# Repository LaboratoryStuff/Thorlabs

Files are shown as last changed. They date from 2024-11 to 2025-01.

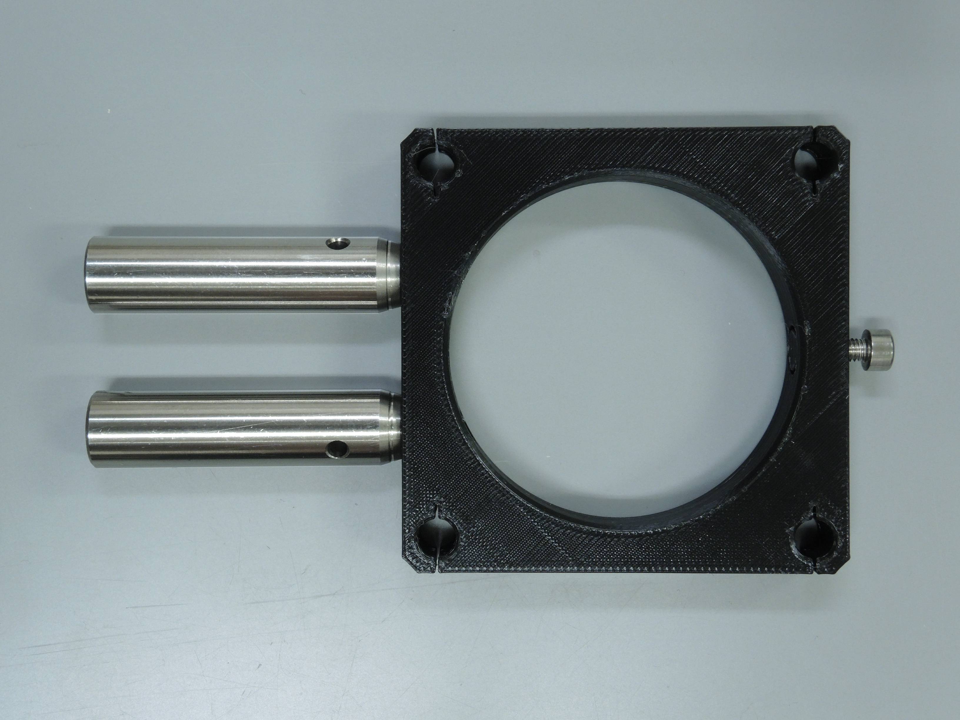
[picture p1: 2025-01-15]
THR-120-010 Cage 60 SM2/Photos/THR-120-010_Photo_05.JPG

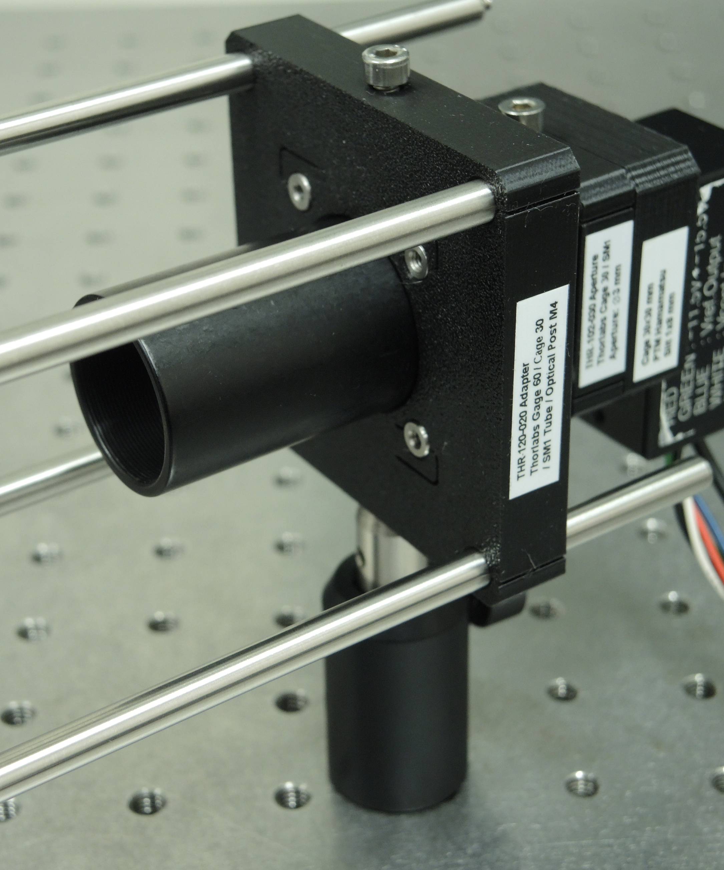
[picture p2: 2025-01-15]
THR-120-020 Cage 60 to 30/Photos/THR-120-020_Photo12.JPG

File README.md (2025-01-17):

# Thorlabs
---

This repository has the following content:
- Motor Stage Class : A Matlab class was developed based on existing code by Andriy Chmyrov (from Helmholtz Zentrum Muenchen), and posteriorly extended by Julan A.J. Fells (from Dept. Engineering Science, University of Oxford). The new class builds on top of the previous class by adding a new Thorlabs series of controllers (Thorlabs BSC201, BSC202 and BSC203), expands the use of the other controllers to work with both rotation and linear stages, adds new functions and makes the class compatible with both 32 and 64-bit Matlab libraries.
- THR-100-010 : Slit 1 mm compatible with Thorlabs Cage 30 mm system and Thorlabs SM1 external tube.
- THR-100-015 : Slit 1.5 mm. Check THR-100-010 for more details.
- THR-100-020 : Slit 2 mm. Check THR-100-010 for more details.
- THR-100-030 : Slit 3 mm. Check THR-100-010 for more details.
- THR-100-050 : Slit 5 mm. Check THR-100-010 for more details.
- THR-101-010 : Adapter, with fixed aperture 5 mm diameter, between Thorlabs Cage 30 mm, Thorlabs SM1 external tube, Thorlabs S05 external tube, optical posts with set screws M4 and Hamamatsu detectors with M2 screw (4 mm deep) grit by 14 x 14 mm. The adapter fits with a width range of photomultipliers (PTM) from Hamamatsu such as the series H9656, H10722, H10723, H11902, H11903, H14603, H16146, H14600/H14601, H14950, H14951, H14990,
H16200, H16201, H16204, H10720, H10721, H11526, H11706, H11900, H11901, H12056, H14600, H14601, H12386, H10682, H11890, H11890, ...
- THR-101-110 : Adapter between Thorlabs Cage 30 mm, Thorlabs SM1 external tube and Hamamatsu detectors with heatsink of the A3179 series.
- THR-102-030 : Fixed aperture 3 mm diameter. Check THR-102-050 for more details.
- THR-102-040 : Fixed aperture 4 mm diameter. Check THR-102-050 for more details.
- THR-102-050 : Fixed aperture 5 mm diameter compatible with Thorlabs Cage 30 mm system, Thorlabs SM1 external tube and optical posts with M4 thread.
- THR-102-060 : Fixed aperture 6 mm diameter. Check THR-102-050 for more details.
- THR-102-070 : Fixed aperture 7 mm diameter. Check THR-102-050 for more details.
- THR-120-010 : Adapter between Thorlabs Cage 60 mm, Thorlabs SM2 external tube and optical post with set screw M4.
- THR-120-020 : Adapter between Thorlabs Cage 60 mm, Thorlabs Cage 30 mm, Thorlabs SM1 external tube and optical post with set screw M4.
- Thorlabs Camera Class: A Matlab class was developed to get images from Thorlabs cameras compatible with uc480DotNet.dll. This class was tested with a single Thorlabs DCC1545M camera and with ThorCam 64-bits. Nonetheless, this class is designed to operate with other Thorlabs cameras of the same family.
- Thorlabs IP250-BV P/N-type laser diodes : Modification of the IP250-BV laser diode drive board to operate with n-type and p-type laser diodes.

---

Content in other repositories compatible with Thorlabs parts:
- JAI repository, JAI-001-010 : Base adapter between JAI camera BM-141GE / BB-141GE with optical posts with M4 or M6 threads.
- JAI repository, JAI-001-020 : Front plate adapeter between JAI camera BM-141GE / BB-141GE with optical posts with M4 thread, Thorlabs Cage 30 mm and Thorlabs SM1 tube.

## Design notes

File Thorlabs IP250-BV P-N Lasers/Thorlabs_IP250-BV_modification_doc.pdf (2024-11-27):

# Thorlabs IP250BV Modifications

Date: 2024-11-27
Author: F.O.

## 1. Summary

The present document describes a modificaon of a Thorlabs IP250-BV laser diode driver board to work with laser diodes of both n and p-type, i.e., with laser diodes with grounded anodes or grounded cathodes. This is accomplished by adding the missing components in posions JMP1, D6 and K2.

## 2. Introducon

Thorlabs offers several laser diode driver boards. Two of these drivers are the Thorlabs IP500 and Thorlabs IP250BV. The last driver is opmised for laser diodes operang with high voltages such as blue-violet lasers (check Thorlabs IP250-BV manual for more details). The main differences of the IP250BV relave to the IP500 are:
- Capable to operate diodes with higher voltages (8 Vdc instead of 3 Vdc);
- Maximum current of 250 mA (instead of 500 mA);
- Can only operate n-type laser diodes (Style B, C and H).

## 3. Board Details

When both boards are compared the head connector JMP1, diode D6 and relay K2 components are missing in the IP250BV board. In the IP500 board, the JMP1 connector selects the laser diode with grounded anodes or cathodes. The K2 relay changes the polarity of the diode connecon. The D6 diode is in parallel with the relay coil (with opposite polarity) to prevent damage to other components when turned off.
Instead of the K2 relay, the IP250-BV board has 2 jumper wires between pins 3-4 and 9-10 (see Figure 1). This corresponds to the de-energized connecons of the relay.

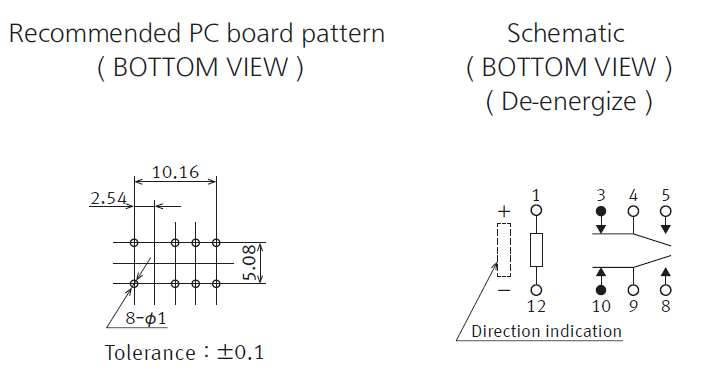
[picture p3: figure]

Figure 1: Schemes of the TX2-12V pins.

The PCB is the same for both laser drivers (boom side: 3037-002, Rev. D, IP1000-PC1). The comparison between an IP250- BV (Front side label: I250-Assy1, Rev. A) and an IP500 (Front side label: I500-Assy1, Rev. D) reveals that only some components are different. In the IP250-BV, the components U1, U2, U3 and U6 are quad FET-input operaonal amplifiers Burr Brown OPA 4137U. In the case of the IP500, U1, U2 and U3 are quad operaonal amplifiers TLC274C and the U6 is a quad operaonal amplifier LMC6484. These components do not change the operaonal funcon of the board. In the IP250-BV the relay is a TX2-12V (12 volts operaon) and in the IP500 the relays are TX2-5V (5 volts operaon).
Secon 5 provides photos of the IP250-BV board and secon 6 provides a list of some of the components of the IP250-BV board.

## 4. Board Modificaon

The IP250-BV can be modified to work with both laser diodes with grounded anodes or grounded cathodes by adding the missing components:
- JMP1: 3-pin male head connector;
- D6 diode: 1N4001;
- K2 relay: TX2-12V (mulple brands available).
Before adding the relay, the jumper wires have to be removed (see Figure 2, red circle).

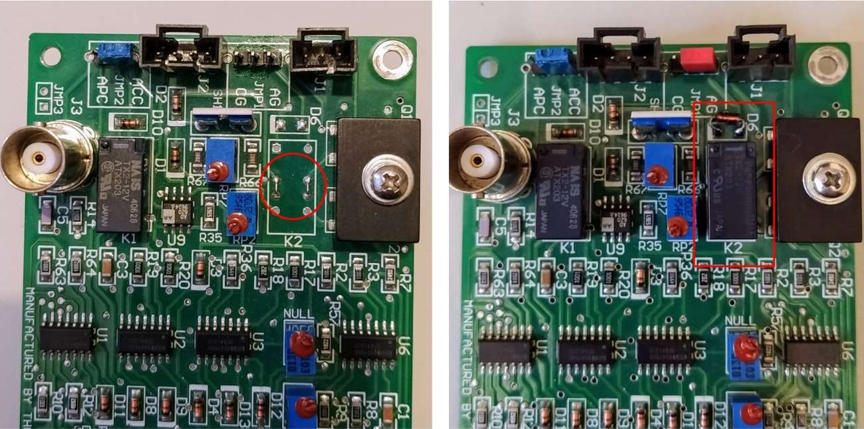
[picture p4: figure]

Figure 2: (le-hand side image) Thorlabs IP250-BV board before adding the D6 and K2 components, JMP1 connector already installed. The red circle shows the jump wires that must be removed before soldering the K2 relay. (right-hand side image) D6 and K2 components installed.

## 5. Board Photos

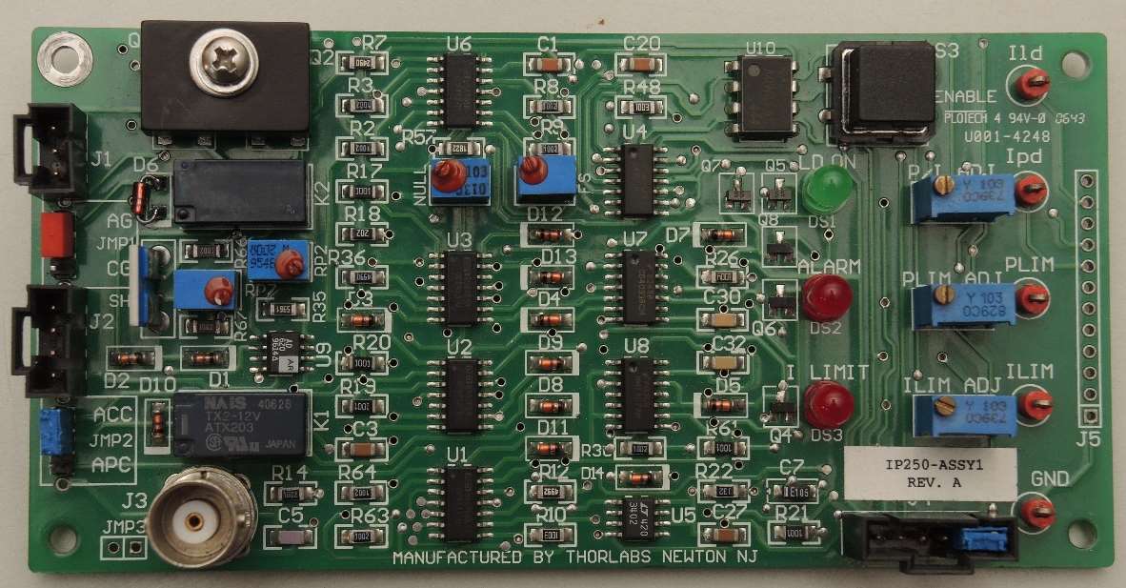
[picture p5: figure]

Figure 3: Thorlabs IP250-BV laser diode driver, top side, aer modificaon (added components JMP1, D6 and K2).

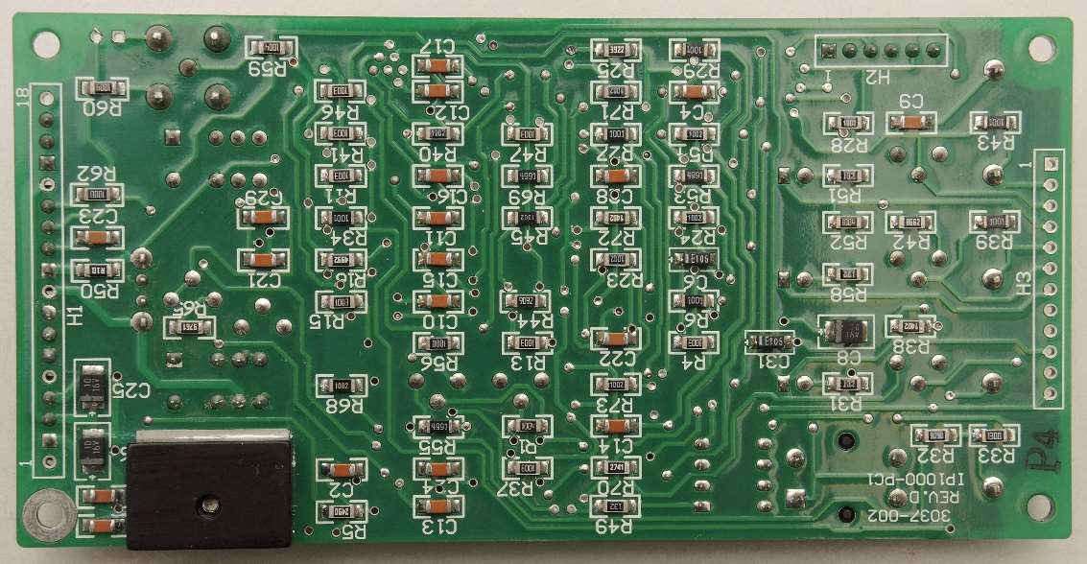
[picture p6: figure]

Figure 4: Thorlabs IP250-BV laser diode driver, boom side.

## 6. List of Components

Table 1: List of some of the components of the board.

Component | Reference | Type
Board | IP250-ASSY1, Rev. A
PCB | 3037-002, Rev. D, IP1000-PC1
U1, U2, U3, U6 | Burr-Brown OPA 4137U | Quad FET Operaonal Amplifiers
U4 | LM339M | Quad Differenal Comparators
U5 | NCS3402 | Dual Comparator
U7 | CD4093BCM | Quad 2-Input NAND, Schmi Triggers
U8 | MM74c74 | Dual D-Type Flip-Flop
U9 | AD620 | Instrumentaon Amplifier
U10 | NAIS AQW212 | Dual Relay
K1 | NAIS TX12-12V | relay 12 V
Q1, Q2 | MJE2955 and MJE3055 | Power Transistors

Q4, Q5, Q6, Q7, Q8 | Panasonic 2SC2405 | NPN transistor SOT-23
SH1 | SR10 | (shunt resistor 1.00 Ω, 1%)
RP2 | Bourns 3266, 200 Ω | Trimpod
RP7, NULL | Bourns 3266, 10 kΩ | Trimpod
FS | trimpod ¼”, 2kΩ | Trimpod
P/I ADJ, PLIM ADJ, ILIM ADJ | Bourns 3296, 10 kΩ | Trimpod

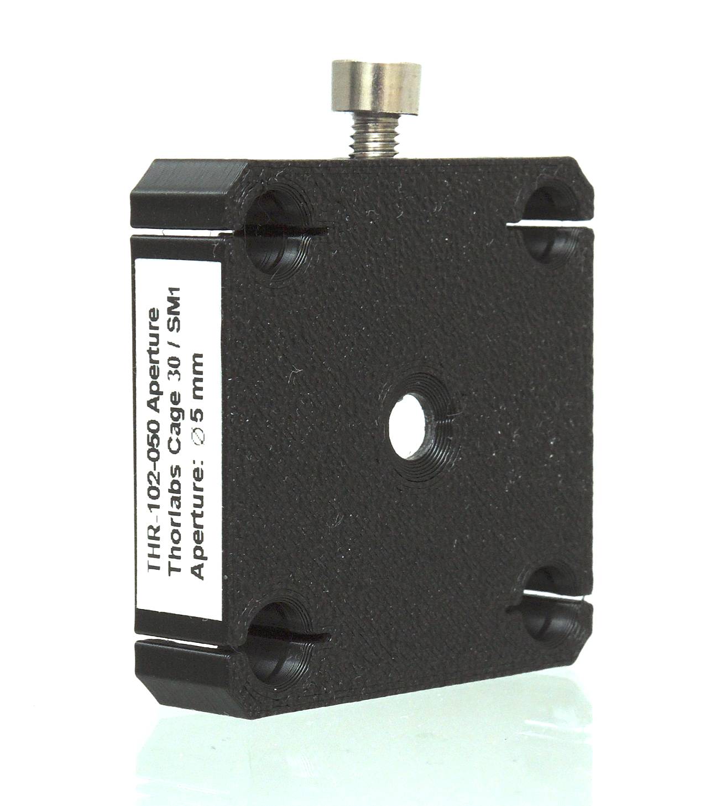
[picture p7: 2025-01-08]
THR-102-050 Aperture 5mm/Photos/THR-102-050_Photo03.JPG

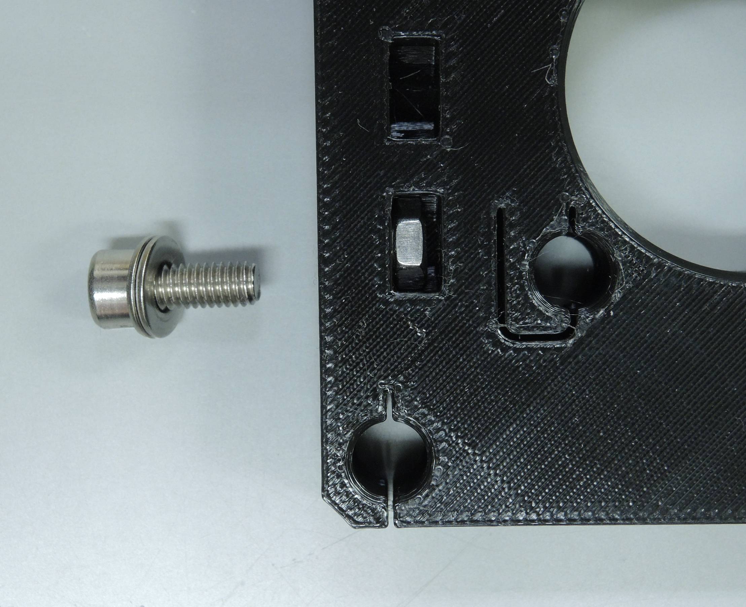
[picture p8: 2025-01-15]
THR-120-020 Cage 60 to 30/Photos/THR-120-020_Photo03_add_nut.JPG

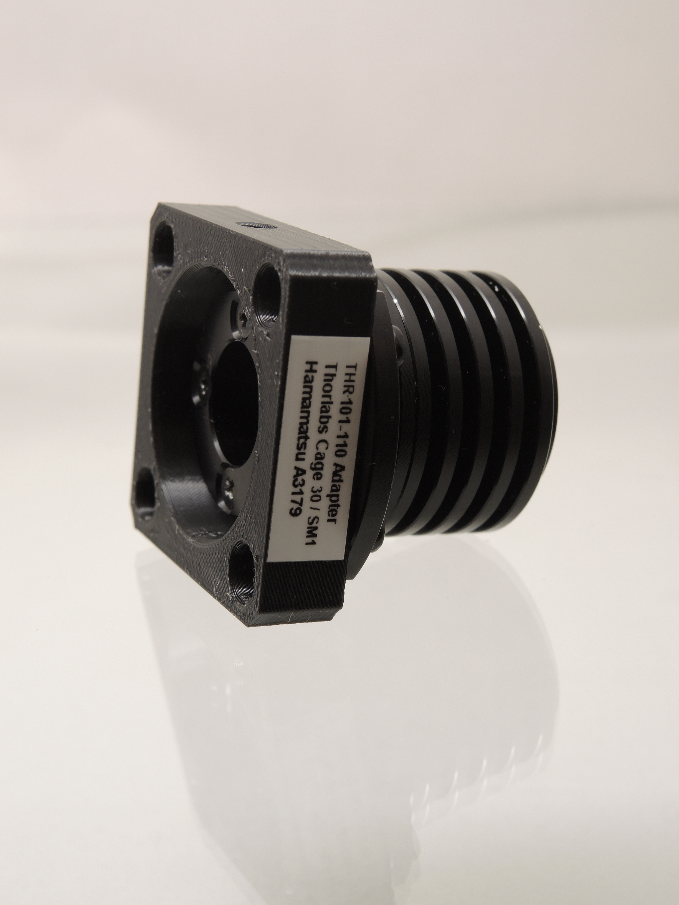
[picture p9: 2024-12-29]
THR-101-110 Cage Hamamatsu A3179/Photos/THR-101-110_Photo01.JPG

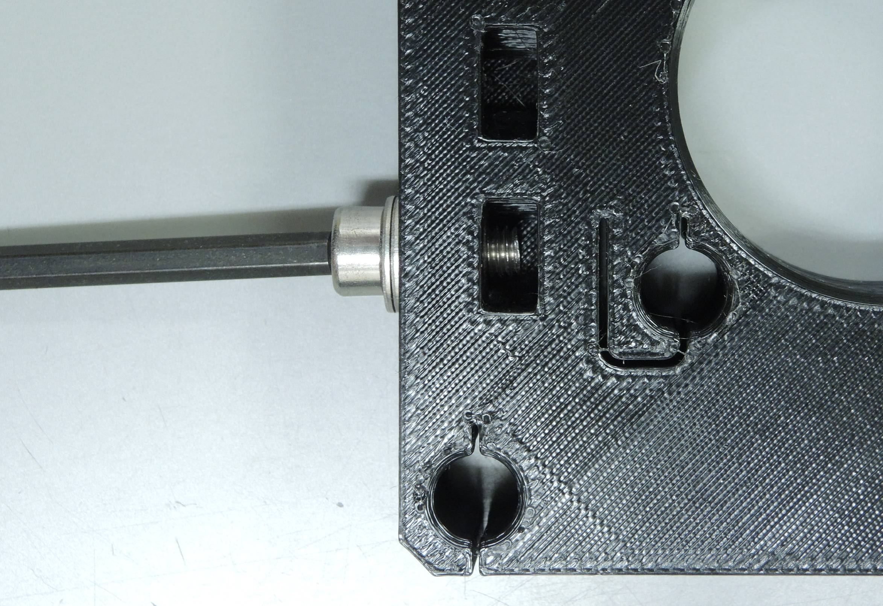
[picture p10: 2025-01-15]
THR-120-020 Cage 60 to 30/Photos/THR-120-020_Photo06_add_nut.JPG

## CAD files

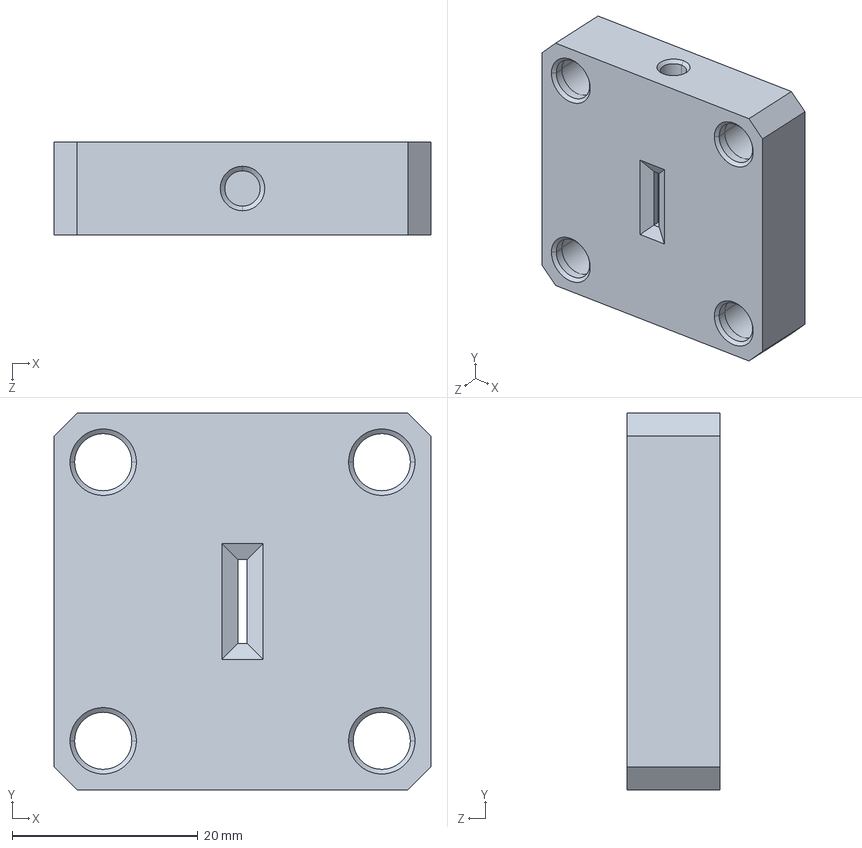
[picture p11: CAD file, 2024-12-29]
THR-100-010 Cage Slit 1mm/STEP/THR-101-010-100_02.STEP
40.6 x 40.6 x 10.0 mm

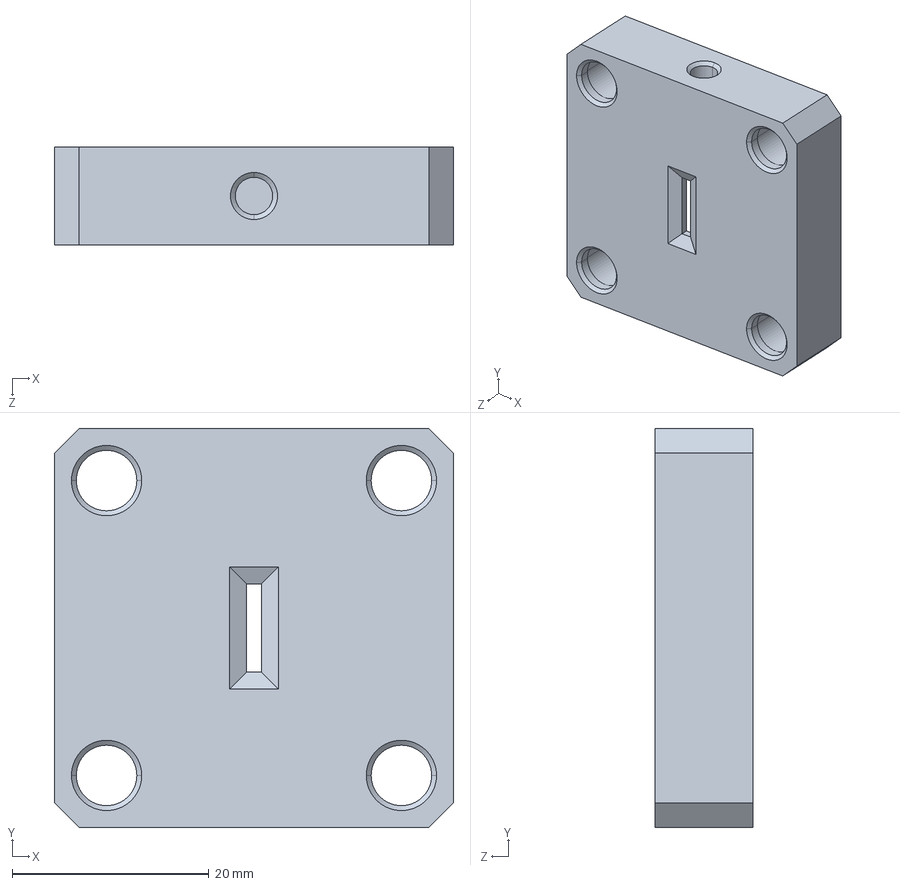
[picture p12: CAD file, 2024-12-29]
THR-100-015 Cage Slit 1_5mm/STEP/THR-100-015-100_02.STEP
40.6 x 40.6 x 10.0 mm

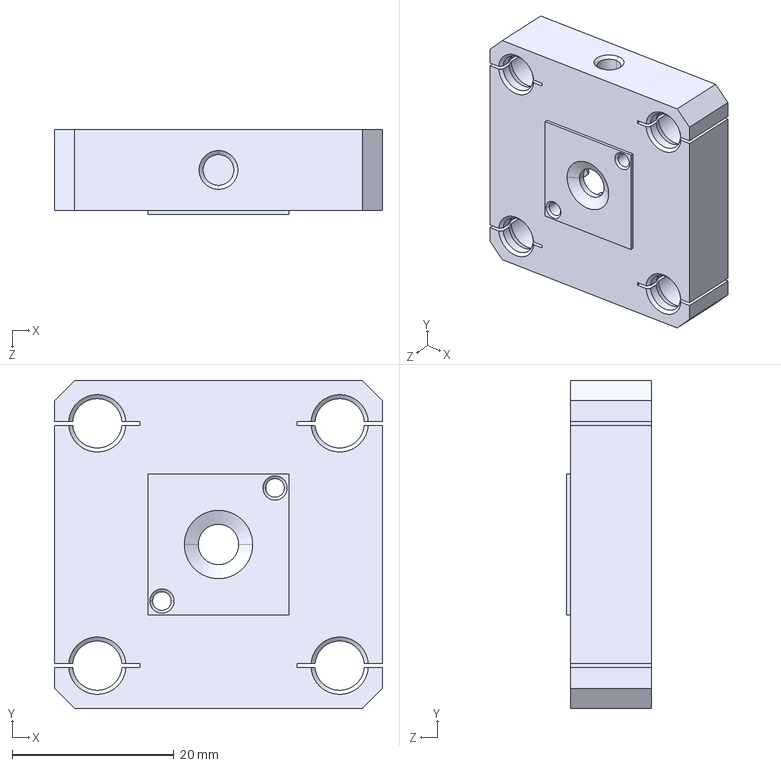
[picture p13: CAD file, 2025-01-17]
THR-101-010 Cage Hamamatsu 14 x 14 mm/STEP/THR-101-010-110_00.STEP
40.6 x 40.6 x 10.5 mm

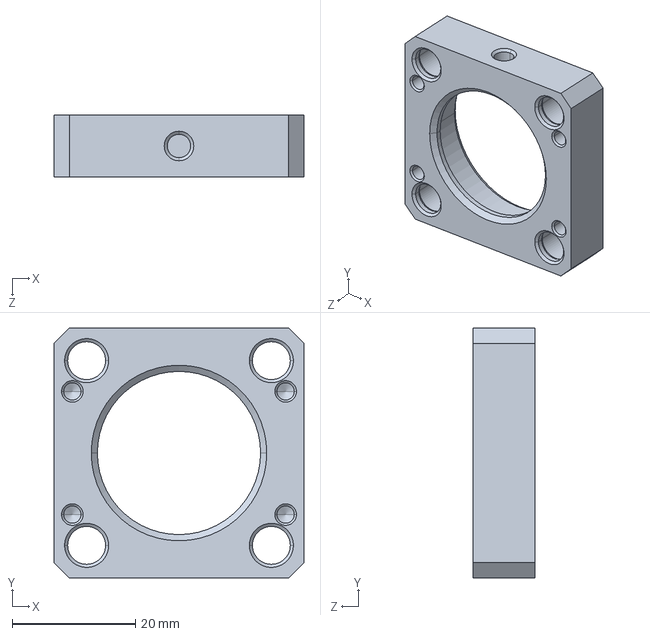
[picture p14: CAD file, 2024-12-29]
THR-101-110 Cage Hamamatsu A3179/STEP/THR-101-110-110_00.STEP
40.6 x 40.6 x 10.0 mm

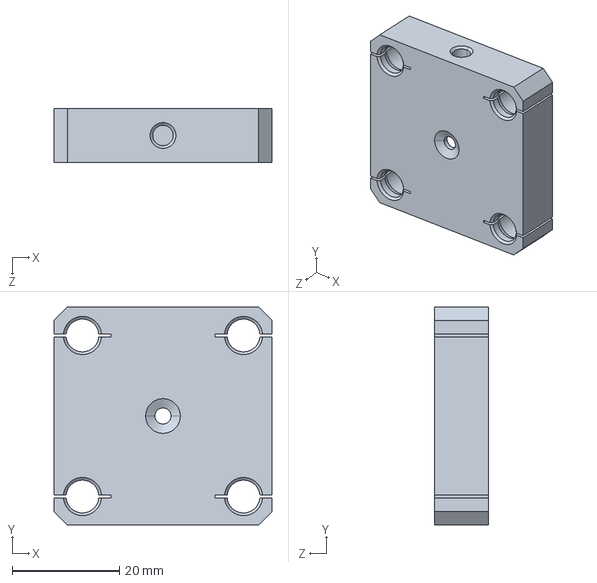
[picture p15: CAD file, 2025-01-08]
THR-102-030 Aperture 3mm/STEP/THR-102-030-110_01.STEP
40.6 x 40.6 x 10.0 mm

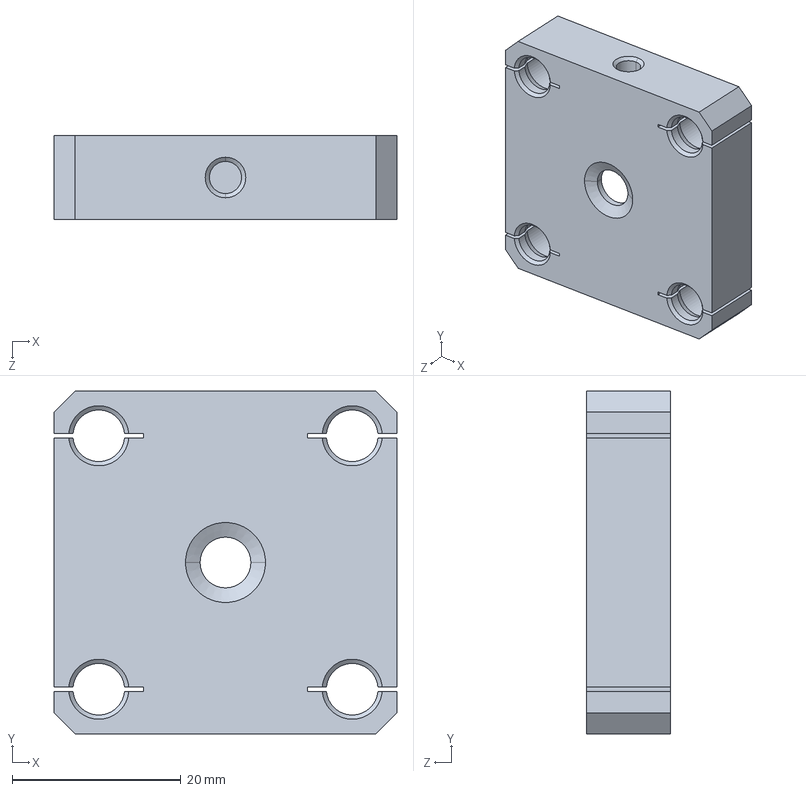
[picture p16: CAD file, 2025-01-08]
THR-102-060 Aperture 6mm/STEP/THR-102-060-110_01.STEP
40.6 x 40.6 x 10.0 mm

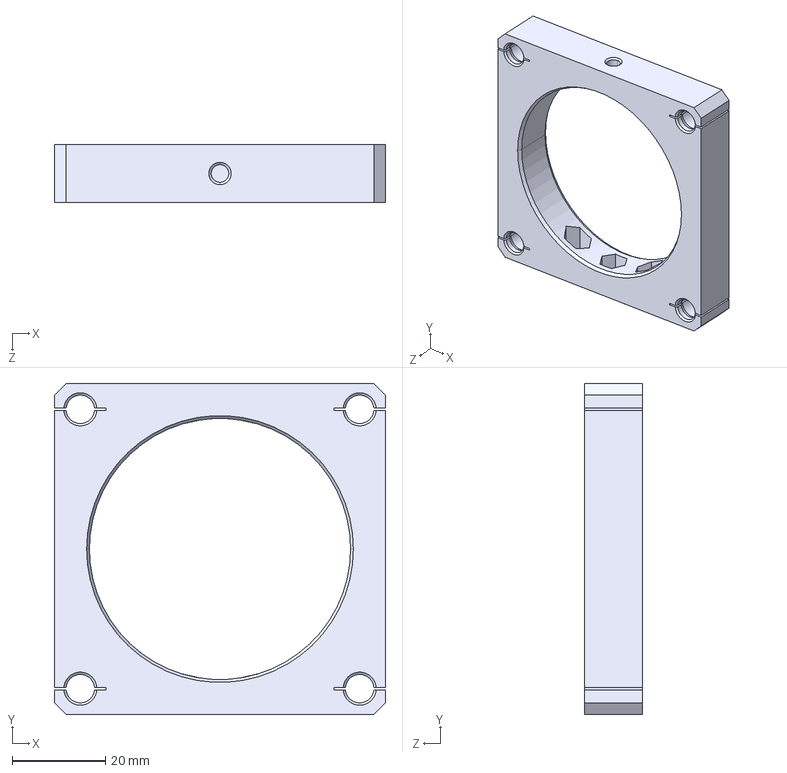
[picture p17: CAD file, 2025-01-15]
THR-120-010 Cage 60 SM2/STEP/THR-120-010-110_00.STEP
71.1 x 71.1 x 12.5 mm

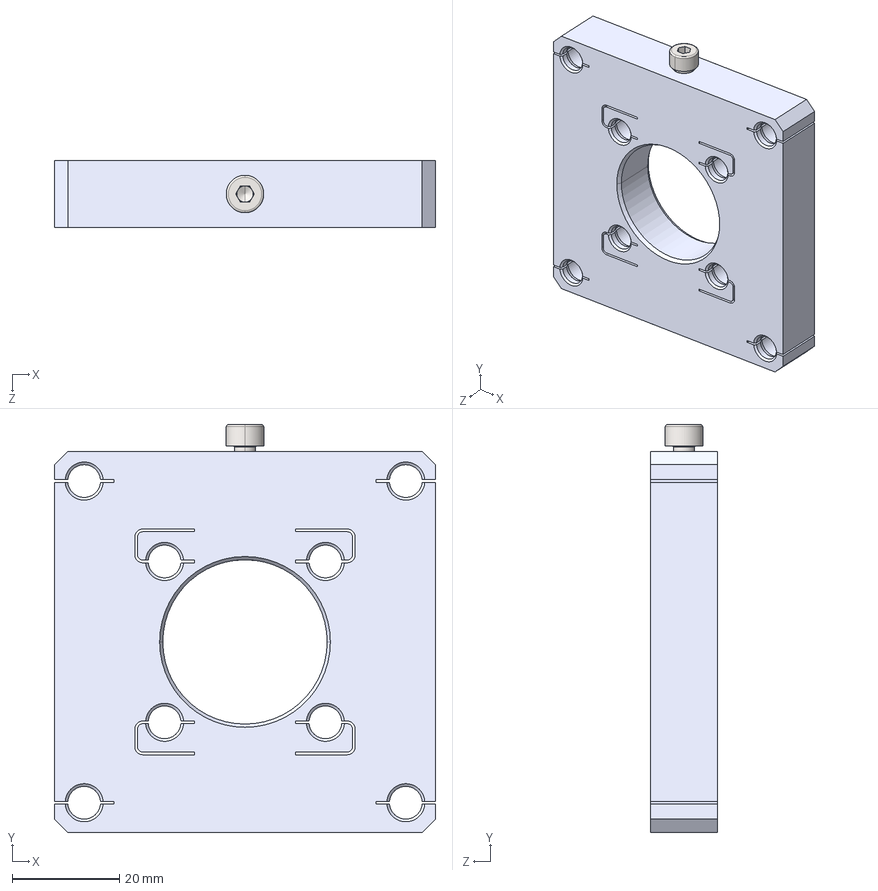
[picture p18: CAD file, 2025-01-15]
THR-120-020 Cage 60 to 30/STEP/THR-120-020-010_00.STEP
71.1 x 76.1 x 12.5 mm
THR-120-020-110_00
socket head cap screw_din_DIN 912 M4 x 20 --- 20N
hex nut style 1 gradeab_din_Hexagon Nut ISO 4032 - M4 - D - N x 3

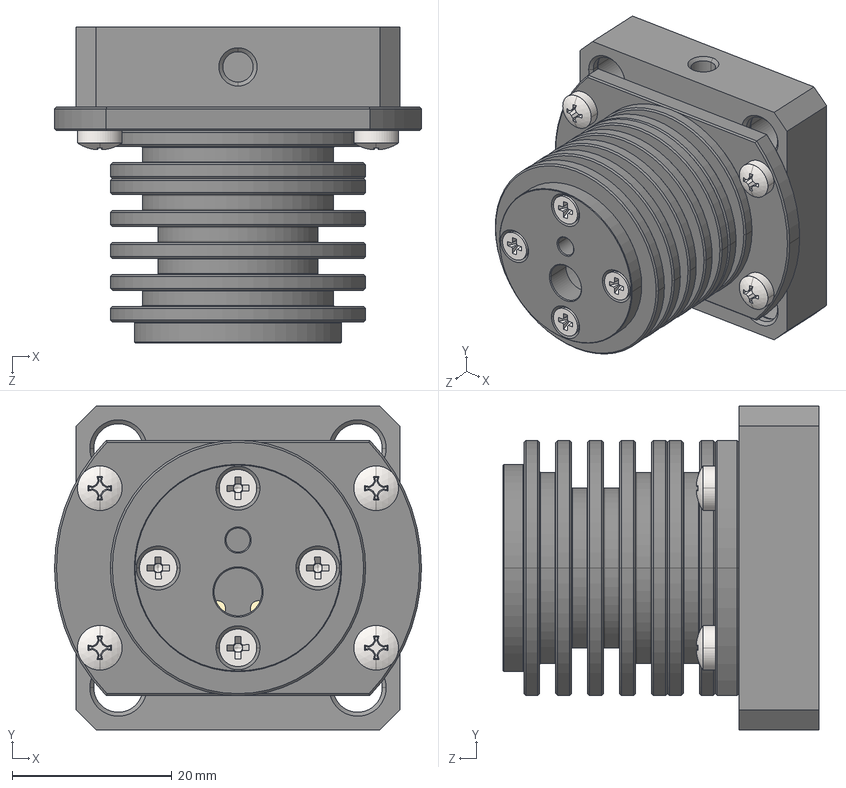
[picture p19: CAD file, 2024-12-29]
THR-101-110 Cage Hamamatsu A3179/STEP/THR-101-110-010_00.STEP
46.0 x 40.6 x 39.6 mm
THR-101-110-110_00
Hamamatsu_A3179_120
Hamamatsu_A3179_210
Hamamatsu_A3179_310
Hamamatsu_A3179_320
countersunk flat head cross recess screw_din_DIN EN ISO 7046-1 - M2.5 x 5 - Z - 5N x 4
countersunk flat head cross recess screw_din_DIN EN ISO 7046-1 - M2.5 x 16 - Z - 16N x 4
sheet metal screws_din_Tapping screw DIN 7049-ST2.9x9.5-C-H-N x 4
Hamamatsu_TO-8_10mm_can
Hamamatsu_TO-8_G12180_1mm_die
Hamamatsu_TO-8_window

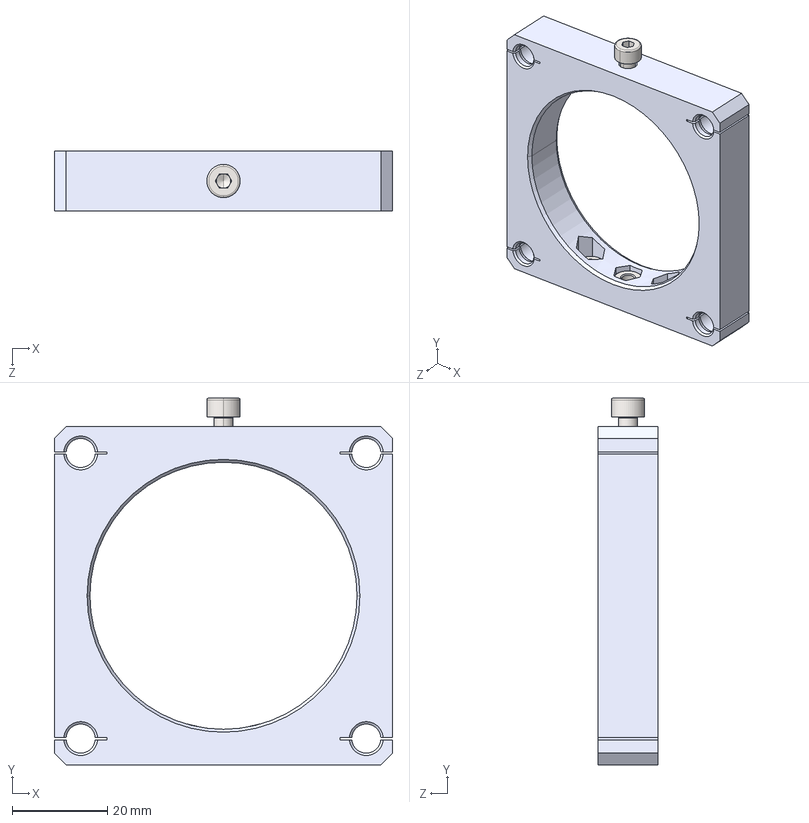
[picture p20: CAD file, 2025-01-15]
THR-120-010 Cage 60 SM2/STEP/THR-120-010-010_00.STEP
71.1 x 77.1 x 12.5 mm
THR-120-010-110_00
socket head cap screw_din_DIN 912 M4 x 8 --- 8N
hex nut style 1 gradeab_din_Hexagon Nut ISO 4032 - M4 - D - N x 3

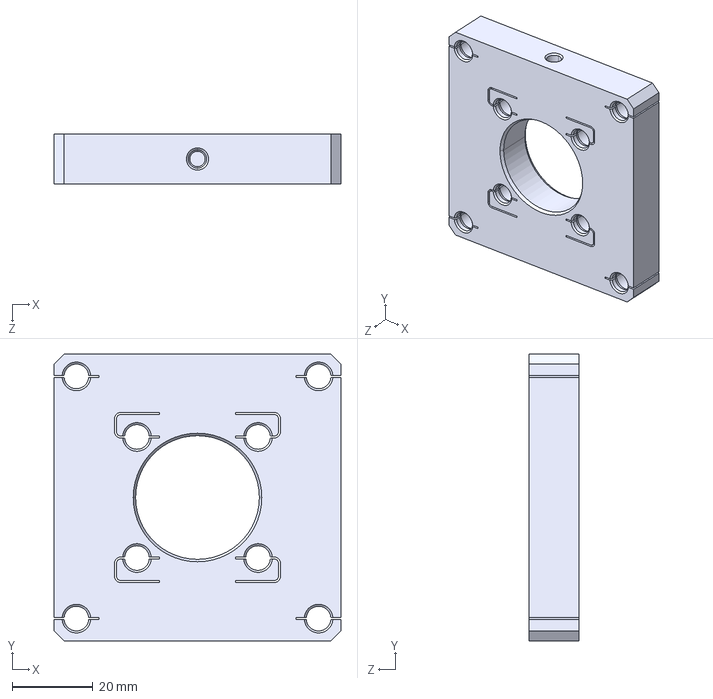
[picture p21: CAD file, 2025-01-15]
THR-120-020 Cage 60 to 30/STEP/THR-120-020-110_00.STEP
71.1 x 71.1 x 12.5 mm

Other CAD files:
THR-100-010 Cage Slit 1mm/STL/THR-100-010-100_02.STL
THR-100-020 Cage Slit 2mm/STEP/THR-100-020-100_02.STEP
THR-100-030 Cage Slit 3mm/STEP/THR-100-030-100_02.STEP
THR-100-050 Cage Slit 5mm/STEP/THR-100-050-100_02.STEP
THR-102-040 Aperture 4mm/STEP/THR-102-040-110_01.STEP
THR-102-050 Aperture 5mm/STEP/THR-102-050-110_01.STEP
THR-102-070 Aperture 7mm/STEP/THR-102-070-110_01.STEP
THR-100-015 Cage Slit 1_5mm/STL/THR-100-015-100_02.STL
THR-100-020 Cage Slit 2mm/STL/THR-100-020-100_02.STL
THR-100-030 Cage Slit 3mm/STL/THR-100-030-100_02.STL
THR-100-050 Cage Slit 5mm/STL/THR-100-050-100_02.STL
THR-101-010 Cage Hamamatsu 14 x 14 mm/STL/THR-101-010-110_00.STL
THR-101-110 Cage Hamamatsu A3179/STL/THR-101-110-110_00.STL
THR-102-030 Aperture 3mm/STL/THR-102-030-110_01.STL
THR-102-040 Aperture 4mm/STL/THR-102-040-110_01.STL
THR-102-050 Aperture 5mm/STL/THR-102-050-110_01.STL
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

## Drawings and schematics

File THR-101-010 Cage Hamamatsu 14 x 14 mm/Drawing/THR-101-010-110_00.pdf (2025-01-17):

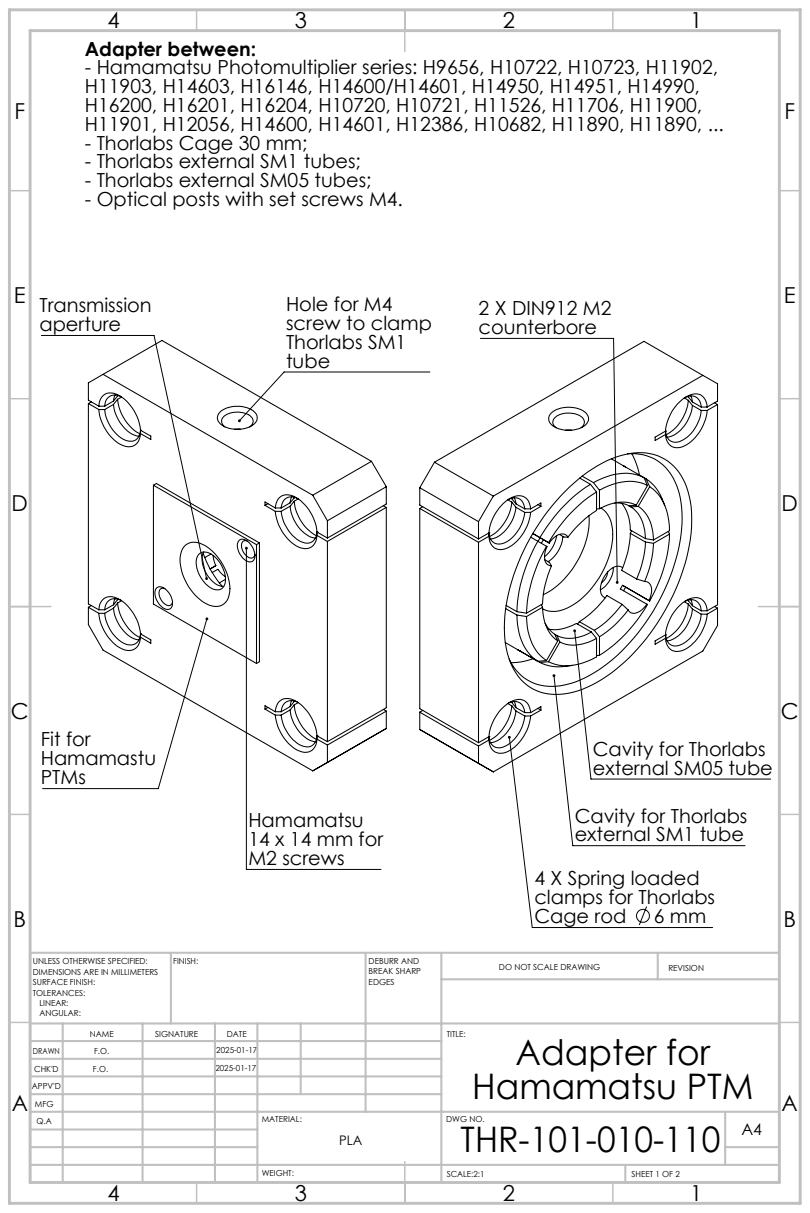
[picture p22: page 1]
2 X DIN912 M2; Fit for; 14 x 14 mm for M2 screws; FINISH:; DEBURR AND; BREAK SHARP; DO NOT SCALE DRAWING; REVISION; SCALE:2:1; SHEET 1 OF 2

Adapter between:
- Hamamatsu Photomultiplier series: H9656, H10722, H10723, H11902,
- Thorlabs Cage 30 mm;
- Thorlabs external SM1 tubes;
- Thorlabs external SM05 tubes;
- Optical posts with set screws M4.

Hole for M4
screw to clamp
Thorlabs SM1
tube

Cavity for Thorlabs
external SM05 tube
external SM1 tube
4 X Spring loaded
clamps for Thorlabs
Cage rod 6 mm

UNLESS OTHERWISE SPECIFIED:
DIMENSIONS ARE IN MILLIMETERS
SURFACE FINISH:
TOLERANCES:
LINEAR:
ANGULAR:

NAME | SIGNATURE | DATE | | | | TITLE: Adapter for Hamamatsu PTM

DRAWN | F.O. | | 2025-01-17
CHK'D | F.O. | | 2025-01-17
APPV'D
MFG
Q.A | | | | MATERIAL: PLA | DWG NO. THR-101-010-110 | A4

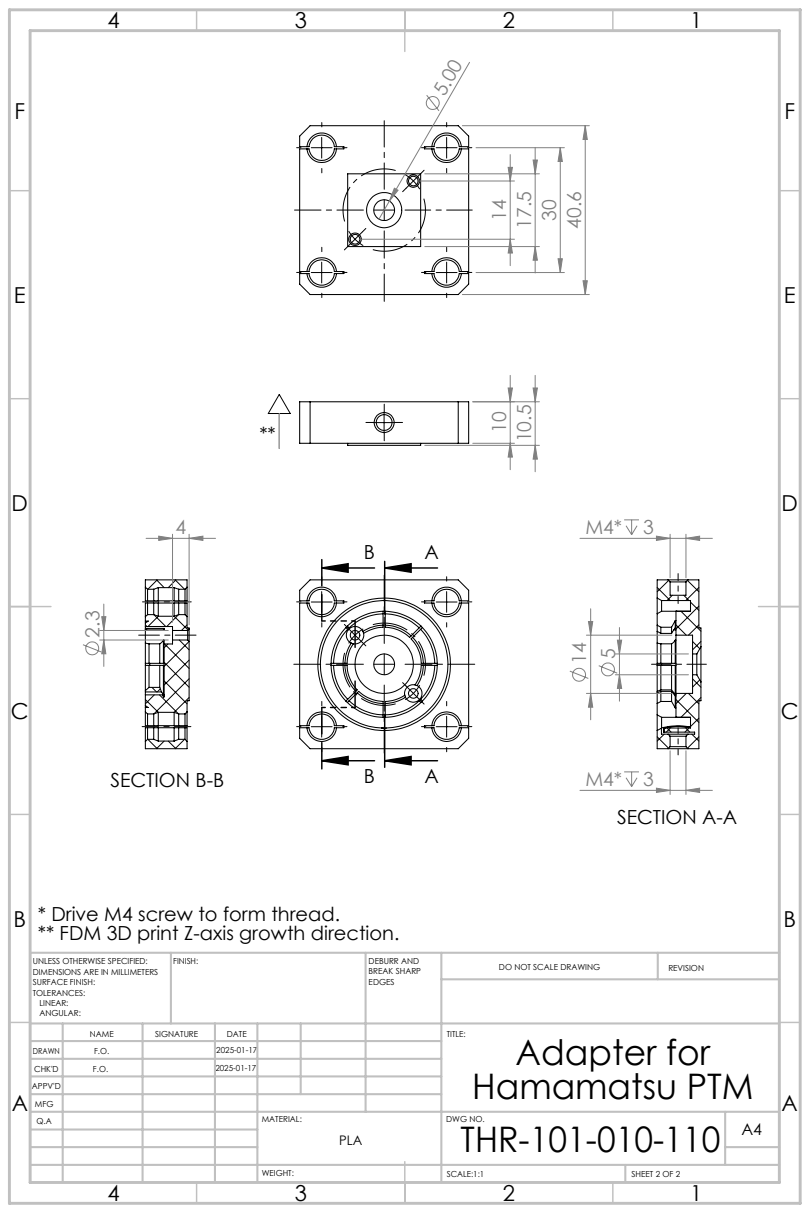
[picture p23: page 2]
SECTION A-A; SECTION B-B; FINISH:; DEBURR AND; BREAK SHARP; DO NOT SCALE DRAWING; REVISION; SCALE:1:1; SHEET 2 OF 2

* Drive M4 screw to form thread.
** FDM 3D print Z-axis growth direction.

UNLESS OTHERWISE SPECIFIED:
DIMENSIONS ARE IN MILLIMETERS
SURFACE FINISH:
TOLERANCES:
LINEAR:
ANGULAR:

NAME | SIGNATURE | DATE | | | | TITLE: Adapter for Hamamatsu PTM

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

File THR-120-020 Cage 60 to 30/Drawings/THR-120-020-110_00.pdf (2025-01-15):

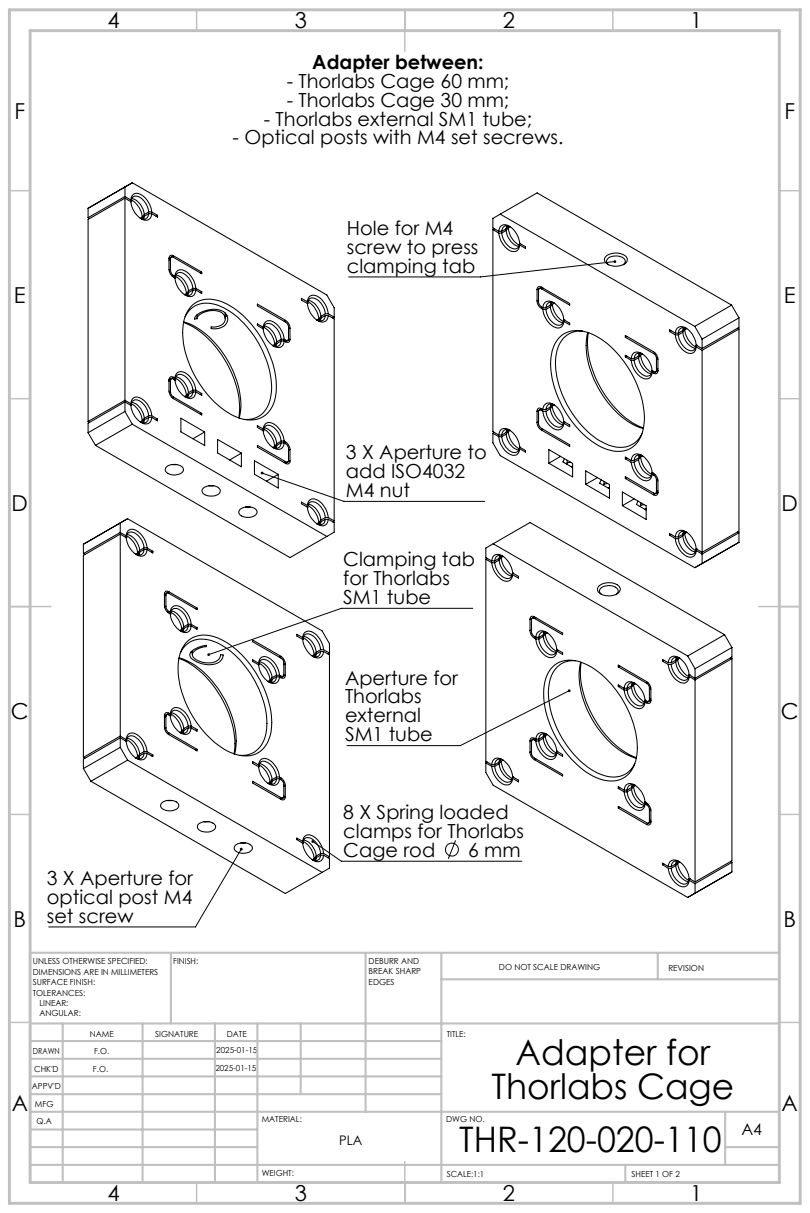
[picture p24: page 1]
3 X Aperture to add ISO4032 M4 nut; Aperture for; SM1 tube; Cage rod; 3 X Aperture for optical post M4 set screw; Clamping tab for Thorlabs SM1 tube; FINISH:; DEBURR AND; BREAK SHARP; DO NOT SCALE DRAWING; REVISION; SCALE:1:1; SHEET 1 OF 2

Adapter between:
- Thorlabs Cage 60 mm;
- Thorlabs Cage 30 mm;
- Thorlabs external SM1 tube;
- Optical posts with M4 set secrews.

Hole for M4
screw to press
clamping tab

8 X Spring loaded
clamps for Thorlabs

UNLESS OTHERWISE SPECIFIED:
DIMENSIONS ARE IN MILLIMETERS
SURFACE FINISH:
TOLERANCES:
LINEAR:
ANGULAR:

NAME | SIGNATURE | DATE | | | | TITLE: Adapter for Thorlabs Cage

DRAWN | F.O. | | 2025-01-15
CHK'D | F.O. | | 2025-01-15
APPV'D
MFG
Q.A | | | | MATERIAL: PLA | DWG NO. THR-120-020-110 | A4

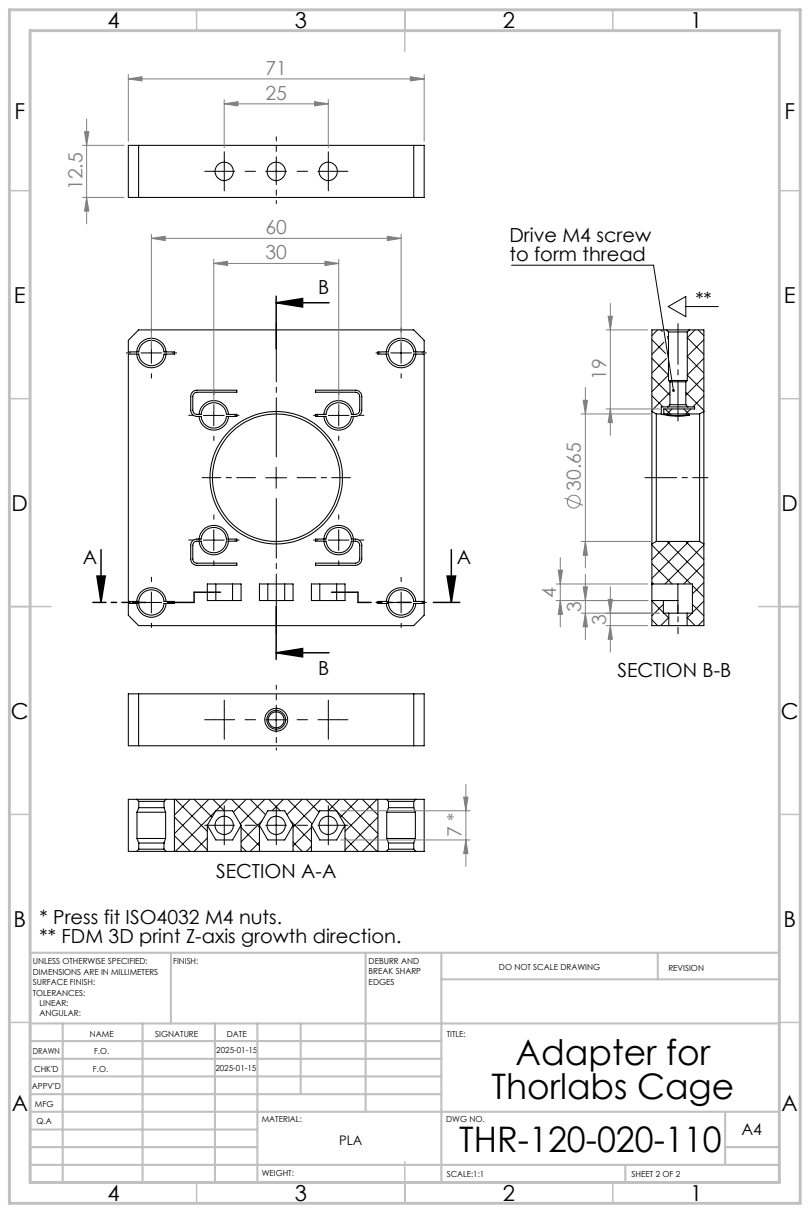
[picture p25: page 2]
SECTION A-A; SECTION B-B; FINISH:; DEBURR AND; BREAK SHARP; DO NOT SCALE DRAWING; REVISION; SCALE:1:1; SHEET 2 OF 2

Drive M4 screw
to form thread

* Press fit ISO4032 M4 nuts.
** FDM 3D print Z-axis growth direction.

UNLESS OTHERWISE SPECIFIED:
DIMENSIONS ARE IN MILLIMETERS
SURFACE FINISH:
TOLERANCES:
LINEAR:
ANGULAR:

NAME | SIGNATURE | DATE | | | | TITLE: Adapter for Thorlabs Cage

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

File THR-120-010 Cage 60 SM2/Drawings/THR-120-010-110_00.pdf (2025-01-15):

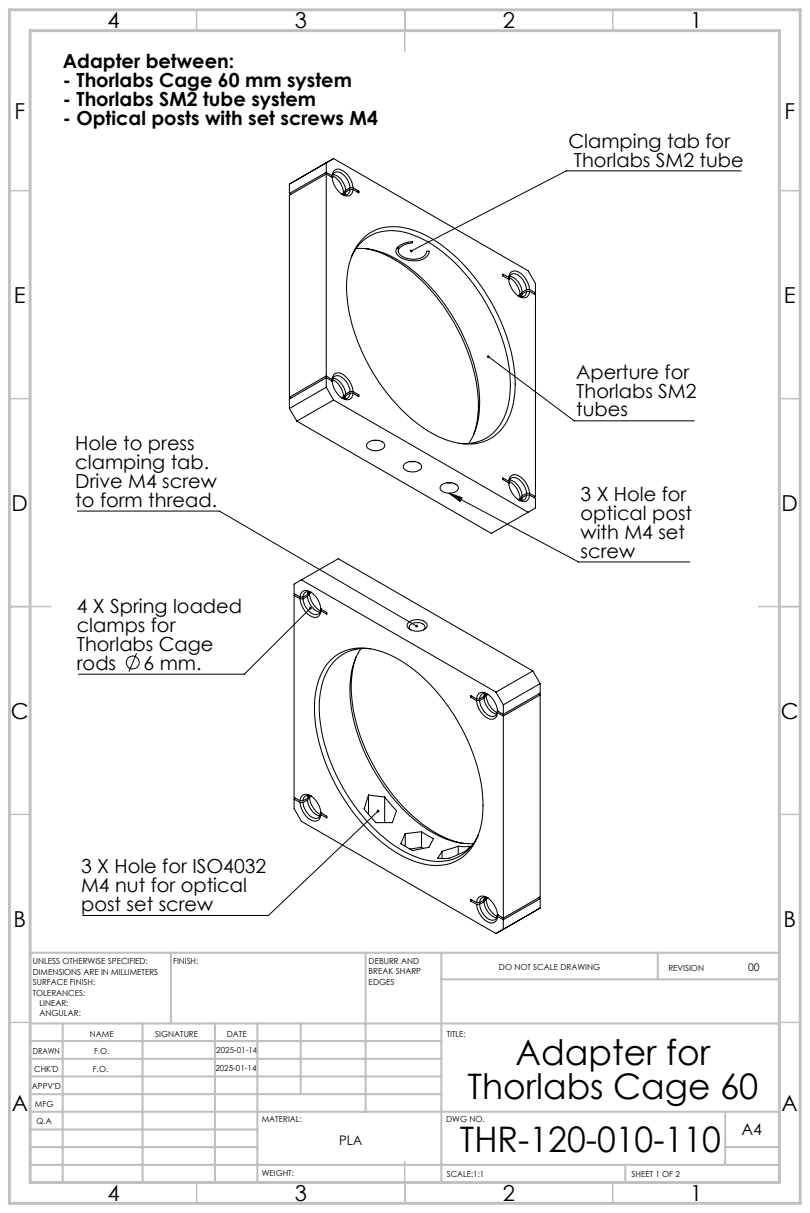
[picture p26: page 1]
4 X Spring loaded clamps for Thorlabs Cage rods 6 mm.; 3 X Hole for optical post with M4 set; Aperture for Thorlabs SM2; FINISH:; DEBURR AND; BREAK SHARP; DO NOT SCALE DRAWING; REVISION; SCALE:1:1; SHEET 1 OF 2

Adapter between:
- Thorlabs Cage 60 mm system
- Thorlabs SM2 tube system
- Optical posts with set screws M4

Clamping tab for
Thorlabs SM2 tube

Hole to press
clamping tab.
Drive M4 screw
to form thread.

3 X Hole for ISO4032
M4 nut for optical
post set screw

UNLESS OTHERWISE SPECIFIED:
DIMENSIONS ARE IN MILLIMETERS
SURFACE FINISH:
TOLERANCES:
LINEAR:
ANGULAR:

NAME | SIGNATURE | DATE | | | | TITLE: Adapter for Thorlabs Cage 60

DRAWN | F.O. | | 2025-01-14
CHK'D | F.O. | | 2025-01-14
APPV'D
MFG
Q.A | | | | MATERIAL: PLA | DWG NO. THR-120-010-110 | A4

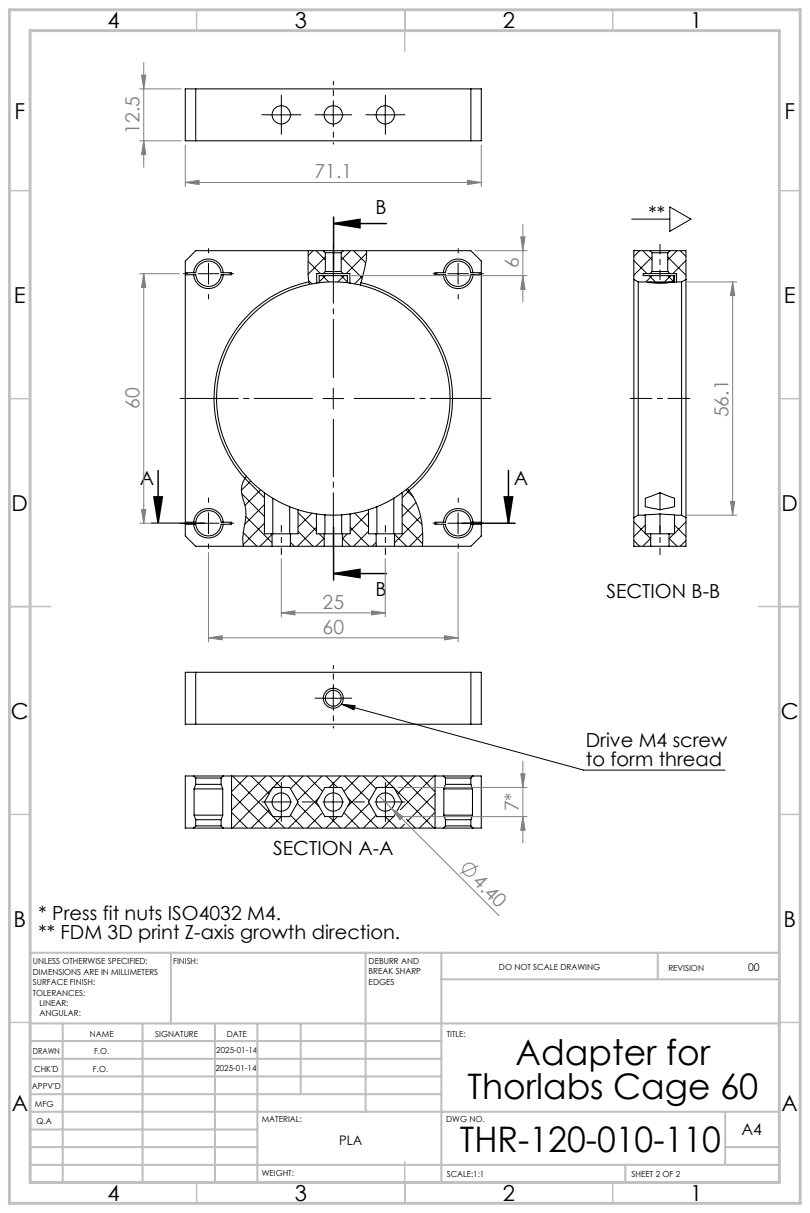
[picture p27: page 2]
SECTION A-A; SECTION B-B; FINISH:; DEBURR AND; BREAK SHARP; DO NOT SCALE DRAWING; REVISION; SCALE:1:1; SHEET 2 OF 2

Drive M4 screw
to form thread

* Press fit nuts ISO4032 M4.
** FDM 3D print Z-axis growth direction.

UNLESS OTHERWISE SPECIFIED:
DIMENSIONS ARE IN MILLIMETERS
SURFACE FINISH:
TOLERANCES:
LINEAR:
ANGULAR:

NAME | SIGNATURE | DATE | | | | TITLE: Adapter for Thorlabs Cage 60

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

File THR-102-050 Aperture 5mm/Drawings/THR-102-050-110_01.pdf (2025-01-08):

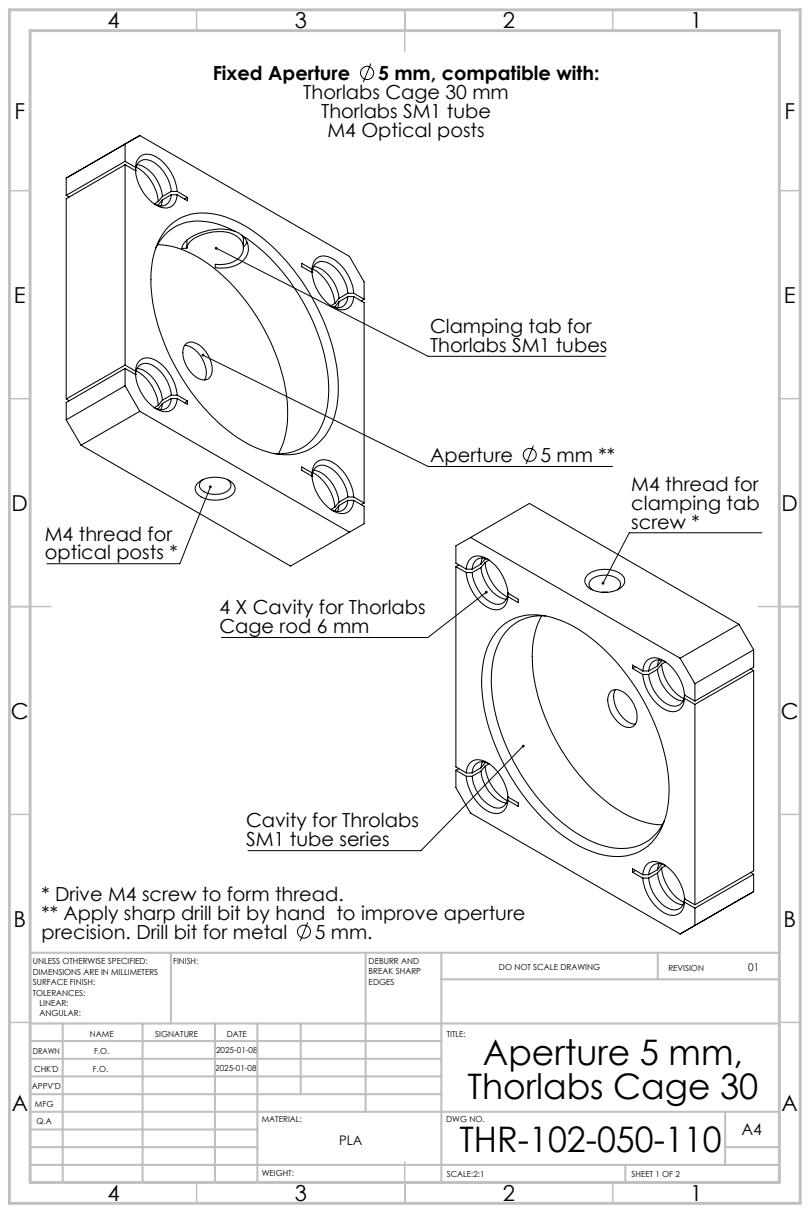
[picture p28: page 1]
M4 thread for clamping tab screw *; Aperture 5 mm **; M4 thread for optical posts *; FINISH:; DEBURR AND; BREAK SHARP; DO NOT SCALE DRAWING; REVISION; SCALE:2:1; SHEET 1 OF 2

Fixed Aperture 5 mm, compatible with:

Thorlabs Cage 30 mm
Thorlabs SM1 tube
M4 Optical posts

Clamping tab for
Thorlabs SM1 tubes

4 X Cavity for Thorlabs
Cage rod 6 mm

Cavity for Throlabs
SM1 tube series

* Drive M4 screw to form thread.
** Apply sharp drill bit by hand to improve aperture
precision. Drill bit for metal 5 mm.

UNLESS OTHERWISE SPECIFIED:
DIMENSIONS ARE IN MILLIMETERS
SURFACE FINISH:
TOLERANCES:
LINEAR:
ANGULAR:

NAME | SIGNATURE | DATE | | | | TITLE: Aperture 5 mm, Thorlabs Cage 30

DRAWN | F.O. | | 2025-01-08
CHK'D | F.O. | | 2025-01-08
APPV'D
MFG
Q.A | | | | MATERIAL: PLA | DWG NO. THR-102-050-110 | A4

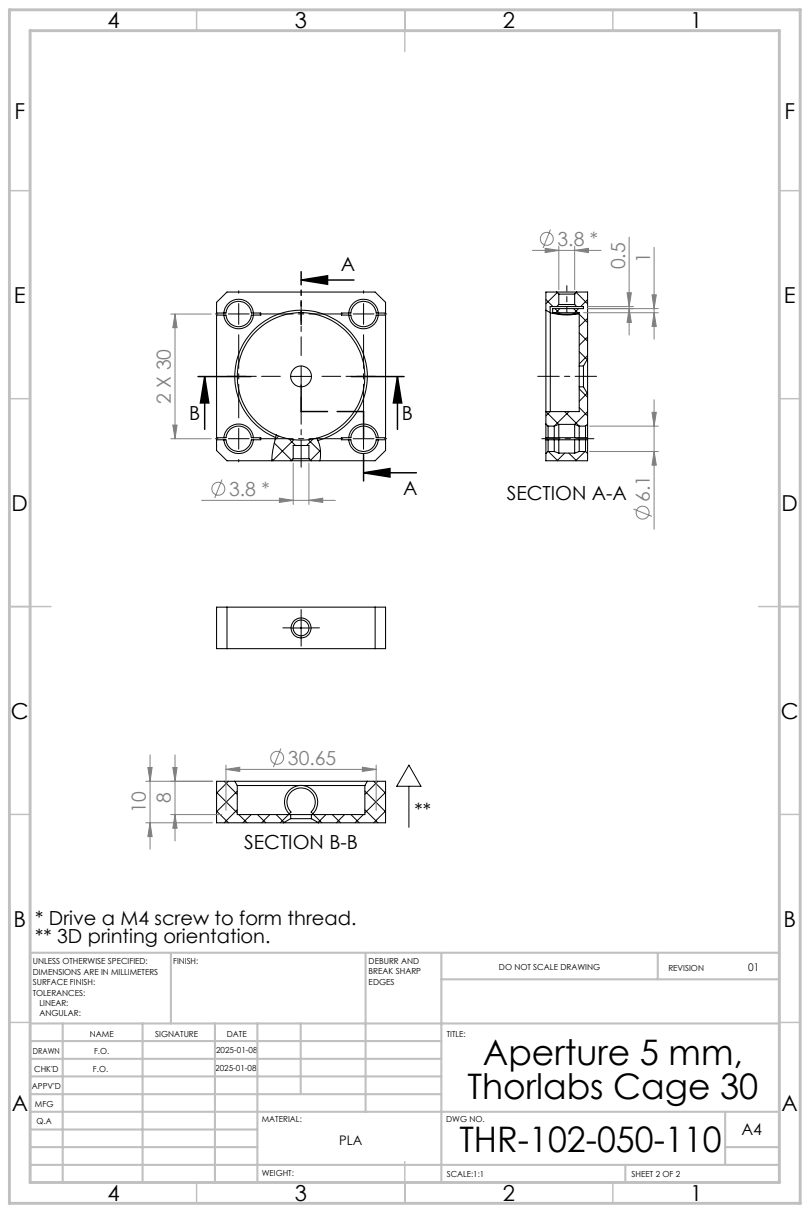
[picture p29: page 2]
SECTION A-A; SECTION B-B; FINISH:; DEBURR AND; BREAK SHARP; DO NOT SCALE DRAWING; REVISION; SCALE:1:1; SHEET 2 OF 2

* Drive a M4 screw to form thread.
** 3D printing orientation.

UNLESS OTHERWISE SPECIFIED:
DIMENSIONS ARE IN MILLIMETERS
SURFACE FINISH:
TOLERANCES:
LINEAR:
ANGULAR:

NAME | SIGNATURE | DATE | | | | TITLE: Aperture 5 mm, Thorlabs Cage 30

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

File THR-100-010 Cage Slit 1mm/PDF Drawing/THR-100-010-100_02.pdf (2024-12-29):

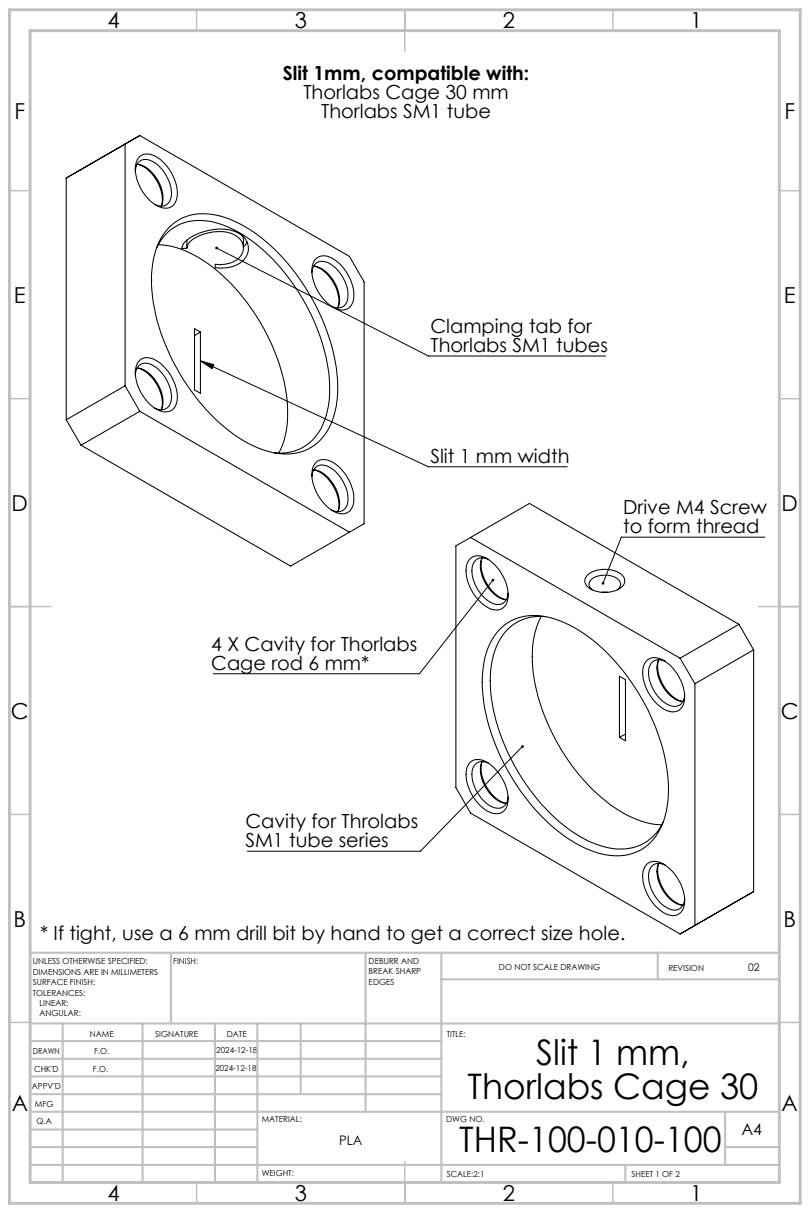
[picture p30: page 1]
FINISH:; DEBURR AND; BREAK SHARP; DO NOT SCALE DRAWING; REVISION; SCALE:2:1; SHEET 1 OF 2

Slit 1mm, compatible with:
Thorlabs Cage 30 mm
Thorlabs SM1 tube

Clamping tab for
Thorlabs SM1 tubes

Slit 1 mm width

Drive M4 Screw
to form thread

4 X Cavity for Thorlabs
Cage rod 6 mm*

Cavity for Throlabs
SM1 tube series

* If tight, use a 6 mm drill bit by hand to get a correct size hole.

UNLESS OTHERWISE SPECIFIED:
DIMENSIONS ARE IN MILLIMETERS
SURFACE FINISH:
TOLERANCES:
LINEAR:
ANGULAR:

NAME | SIGNATURE | DATE | | | | TITLE: Slit 1 mm, Thorlabs Cage 30

DRAWN | F.O. | | 2024-12-18
CHK'D | F.O. | | 2024-12-18
APPV'D
MFG
Q.A | | | | MATERIAL: PLA | DWG NO. THR-100-010-100 | A4

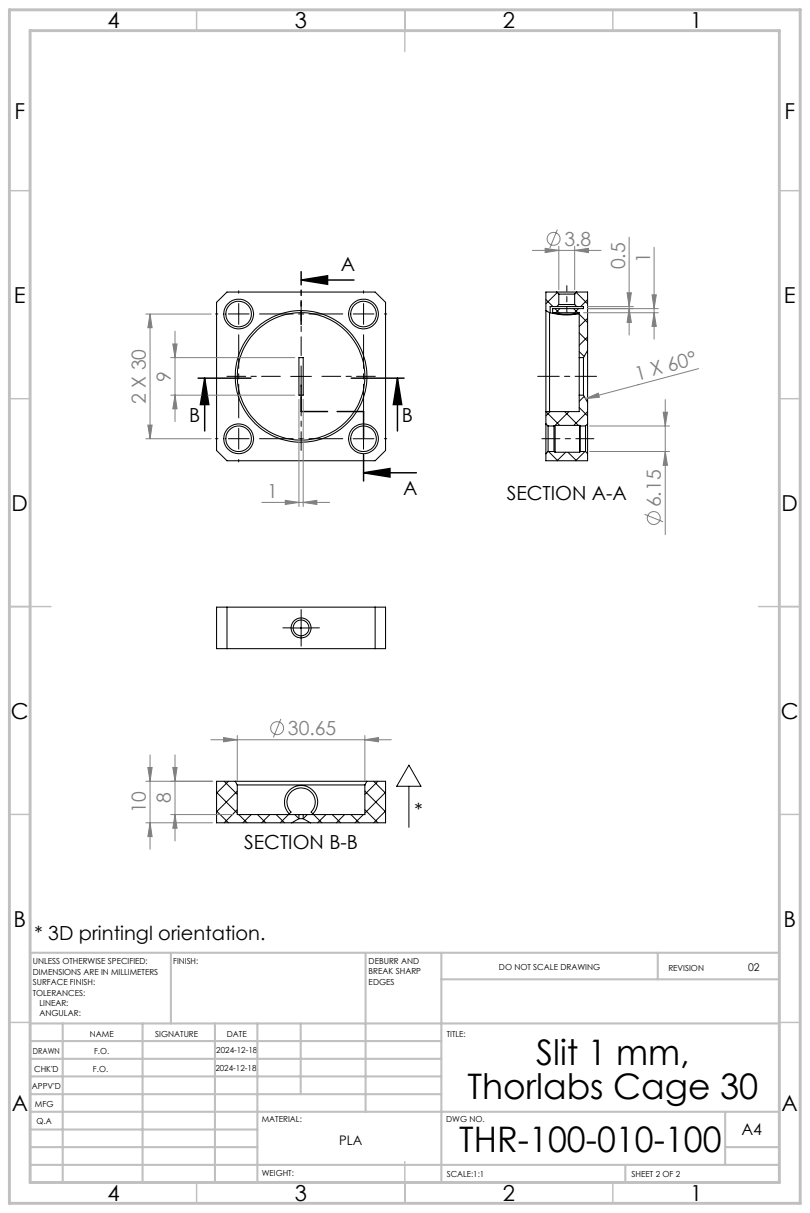
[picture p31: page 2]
* 3D printingl orientation.; SECTION A-A; SECTION B-B; FINISH:; DEBURR AND; BREAK SHARP; DO NOT SCALE DRAWING; REVISION; SCALE:1:1; SHEET 2 OF 2

UNLESS OTHERWISE SPECIFIED:
DIMENSIONS ARE IN MILLIMETERS
SURFACE FINISH:
TOLERANCES:
LINEAR:
ANGULAR:

NAME | SIGNATURE | DATE | | | | TITLE: Slit 1 mm, Thorlabs Cage 30

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

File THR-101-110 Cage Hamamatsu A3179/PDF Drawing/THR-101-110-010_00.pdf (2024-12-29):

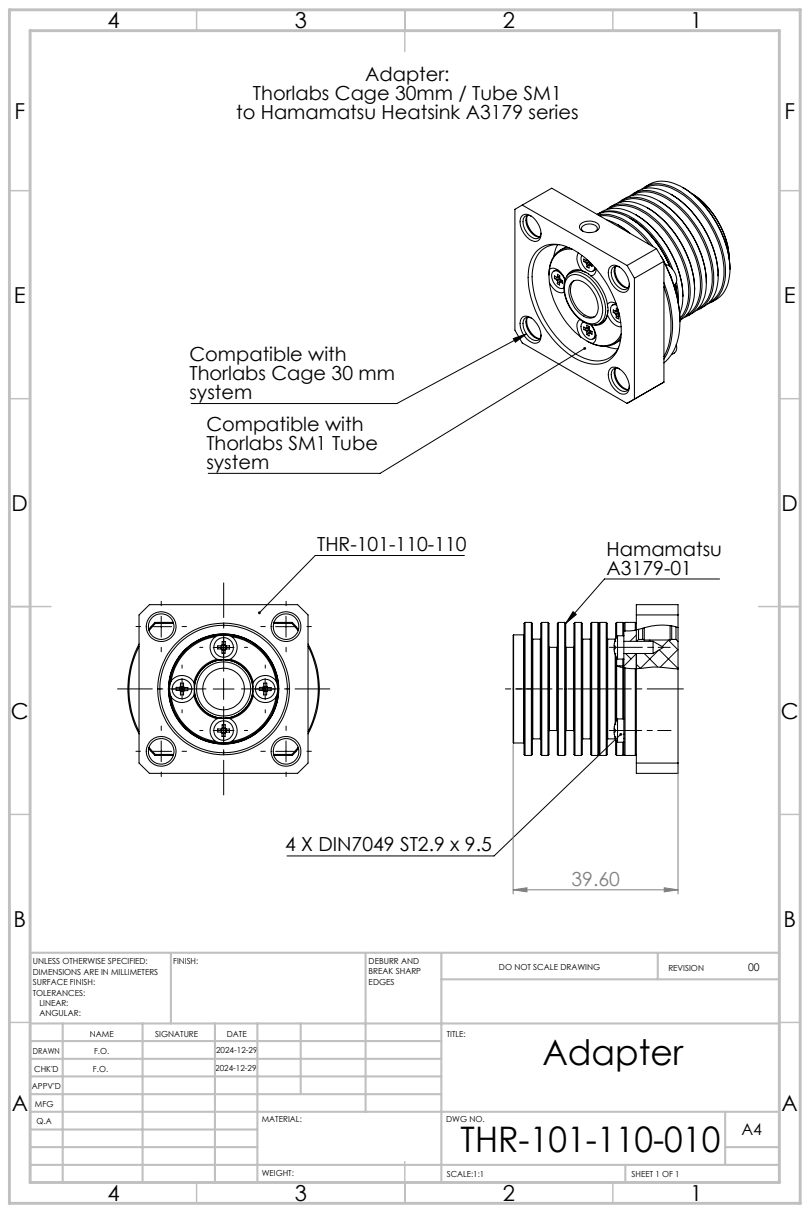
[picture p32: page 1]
4 X DIN7049 ST2.9 x 9.5; FINISH:; DEBURR AND; BREAK SHARP; DO NOT SCALE DRAWING; REVISION; SCALE:1:1; SHEET 1 OF 1

Thorlabs Cage 30mm / Tube SM1
to Hamamatsu Heatsink A3179 series

Compatible with
Thorlabs Cage 30 mm
system
Thorlabs SM1 Tube

UNLESS OTHERWISE SPECIFIED:
DIMENSIONS ARE IN MILLIMETERS
SURFACE FINISH:
TOLERANCES:
LINEAR:
ANGULAR:

NAME | SIGNATURE | DATE | | | | TITLE: Adapter

DRAWN | F.O. | | 2024-12-29
CHK'D | F.O. | | 2024-12-29
APPV'D
MFG
Q.A | | | | MATERIAL: | DWG NO. THR-101-110-010 | A4

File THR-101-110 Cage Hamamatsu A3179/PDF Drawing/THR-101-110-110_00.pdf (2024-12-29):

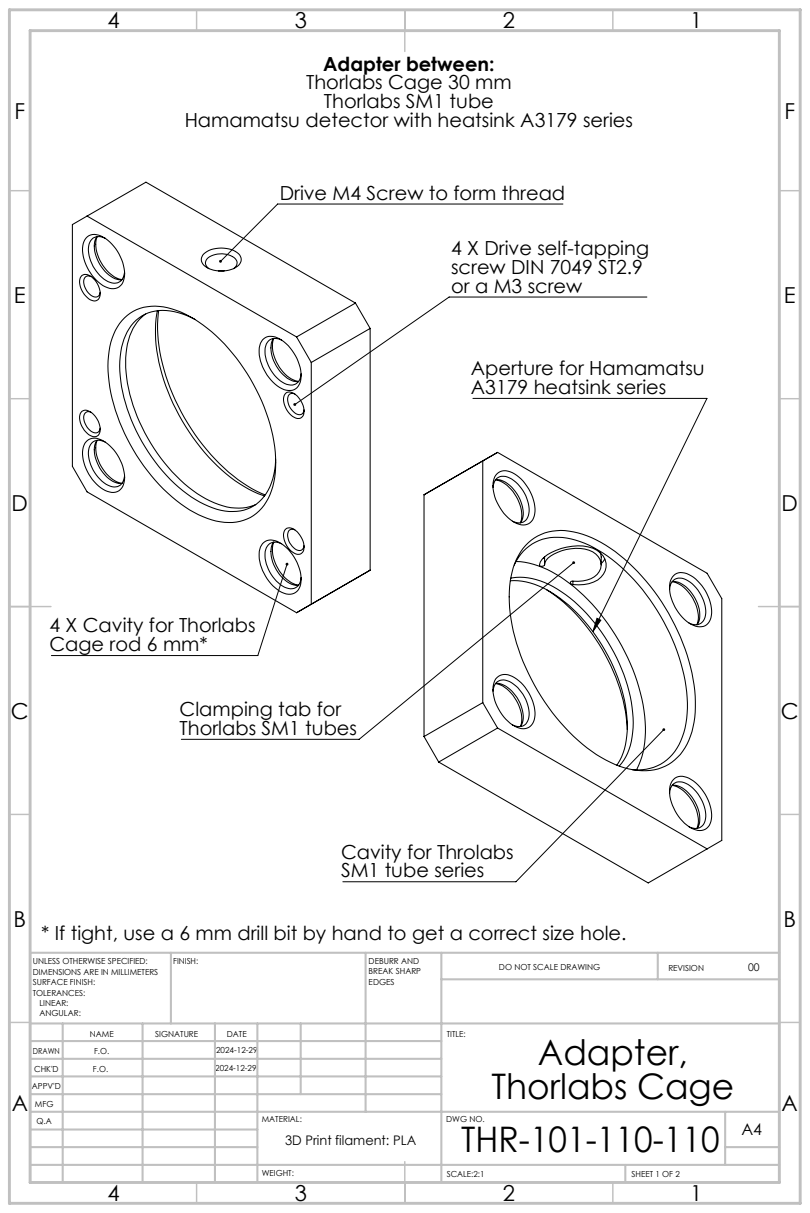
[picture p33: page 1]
FINISH:; DEBURR AND; BREAK SHARP; DO NOT SCALE DRAWING; REVISION; SCALE:2:1; SHEET 1 OF 2

Adapter between:
Thorlabs Cage 30 mm
Thorlabs SM1 tube

Hamamatsu detector with heatsink A3179 series

Drive M4 Screw to form thread

4 X Drive self-tapping
screw DIN 7049 ST2.9
or a M3 screw

Aperture for Hamamatsu
A3179 heatsink series

4 X Cavity for Thorlabs
Cage rod 6 mm*

Clamping tab for
Thorlabs SM1 tubes

Cavity for Throlabs
SM1 tube series

* If tight, use a 6 mm drill bit by hand to get a correct size hole.

UNLESS OTHERWISE SPECIFIED:
DIMENSIONS ARE IN MILLIMETERS
SURFACE FINISH:
TOLERANCES:
LINEAR:
ANGULAR:

NAME | SIGNATURE | DATE | | | | TITLE: Adapter, Thorlabs Cage

DRAWN | F.O. | | 2024-12-29
CHK'D | F.O. | | 2024-12-29
APPV'D
MFG
Q.A | | | | MATERIAL: | DWG NO. THR-101-110-110 | A4 3D Print filament: PLA

* 3D printingl orientation.; FINISH:; DEBURR AND; BREAK SHARP; DO NOT SCALE DRAWING; REVISION; SCALE:1:1; SHEET 2 OF 2

UNLESS OTHERWISE SPECIFIED:
DIMENSIONS ARE IN MILLIMETERS
SURFACE FINISH:
TOLERANCES:
LINEAR:
ANGULAR:

NAME | SIGNATURE | DATE | | | | TITLE: Adapter, Thorlabs Cage

DRAWN | F.O. | | 2024-12-29
CHK'D | F.O. | | 2029-12-29
APPV'D
MFG
Q.A | | | | MATERIAL: PLA | DWG NO. THR-101-110-110 | A4
